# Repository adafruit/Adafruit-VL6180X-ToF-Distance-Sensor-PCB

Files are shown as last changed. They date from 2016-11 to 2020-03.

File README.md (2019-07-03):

## Adafruit VL6180X ToF Distance Sensor PCB

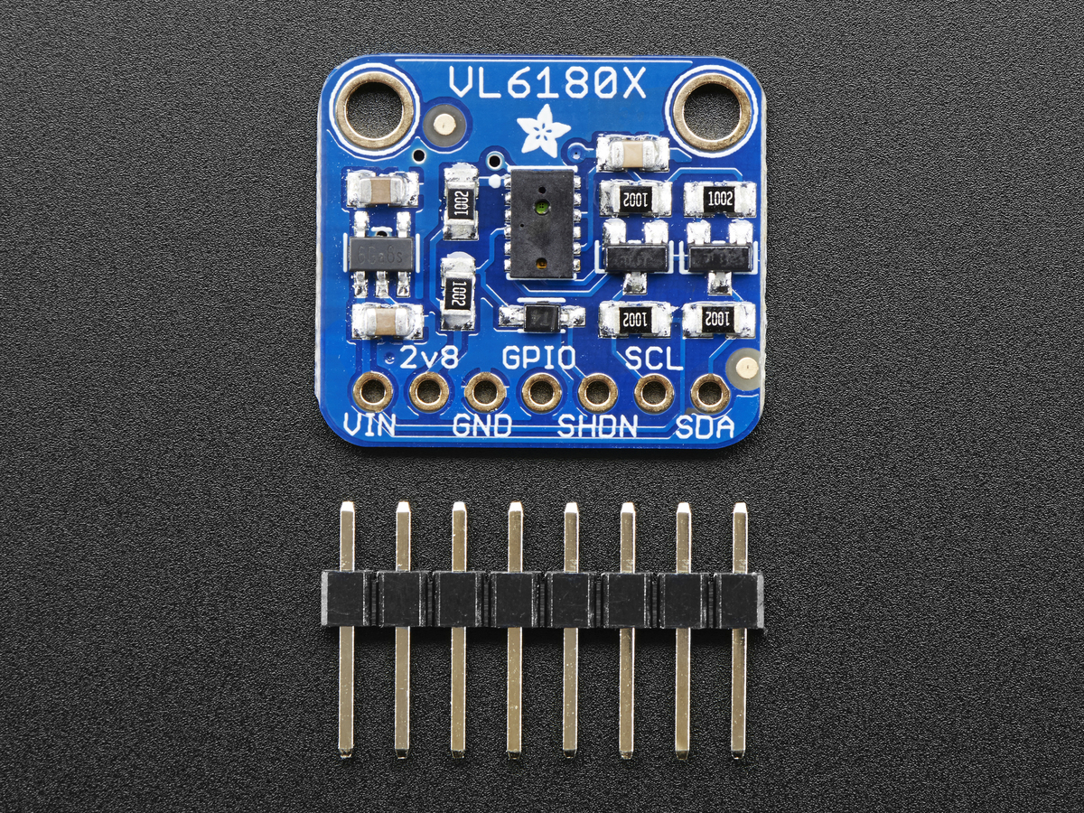
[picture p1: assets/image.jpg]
<a href="http://www.adafruit.com/products/3316"><br/>
Click here to purchase one from the Adafruit shop</a>

PCB files for the Adafruit VL6180X (VL6180) ToF Distance Sensor. Format is EagleCAD schematic and board layout

For more details, check out the product page at
* https://www.adafruit.com/product/3316

### Description

The VL6180X (sometimes called the VL6180) is a Time of Flight distance sensor like no other you've used! The sensor contains a very tiny laser source, and a matching sensor. The VL6180X can detect the "time of flight", or how long the laser light has taken to bounce back to the sensor. Since it uses a very narrow light source, it is good for determining distance of only the surface directly in front of it.

Unlike sonars that bounce ultrasonic waves, the 'cone' of sensing is very narrow. Unlike IR distance sensors that try to measure the amount of light bounced, the VL6180X is much more precise and doesn't have linearity problems or 'double imaging' where you can't tell if an object is very far or very close.

This is the 'little sister' of the Adafruit VL53L0X ToF sensor, and can handle about 5mm to 100mm of range distance. We've seen up to 150-200mm with good ambient conditions. It also includes a lux sensor. If you need a larger range, check out the VL53L0X which can measure 50 - 1200 mm.

The sensor is small and easy to use in any robotics or interactive project. Since it needs 2.8V power and logic we put the little fellow on a breakout board with a regulator and level shifting. You can use it with any 3-5V power or logic microcontroller with no worries. Each order comes with a small piece of header. Solder the header onto your breakout board with your iron and some solder and wire it up for instant distance-sensing-success!

Communicating to the sensor is done over I2C with some simple commands. Most of the work is handled inside the sensor itself, so its very easy to port our Arduino library to another microcontroller.

### License

Adafruit invests time and resources providing this open source design, please support Adafruit and open-source hardware by purchasing products from [Adafruit](https://www.adafruit.com)!

Designed by Limor Fried/Ladyada for Adafruit Industries.

Creative Commons Attribution/Share-Alike, all text above must be included in any redistribution. See license.txt for additional details.

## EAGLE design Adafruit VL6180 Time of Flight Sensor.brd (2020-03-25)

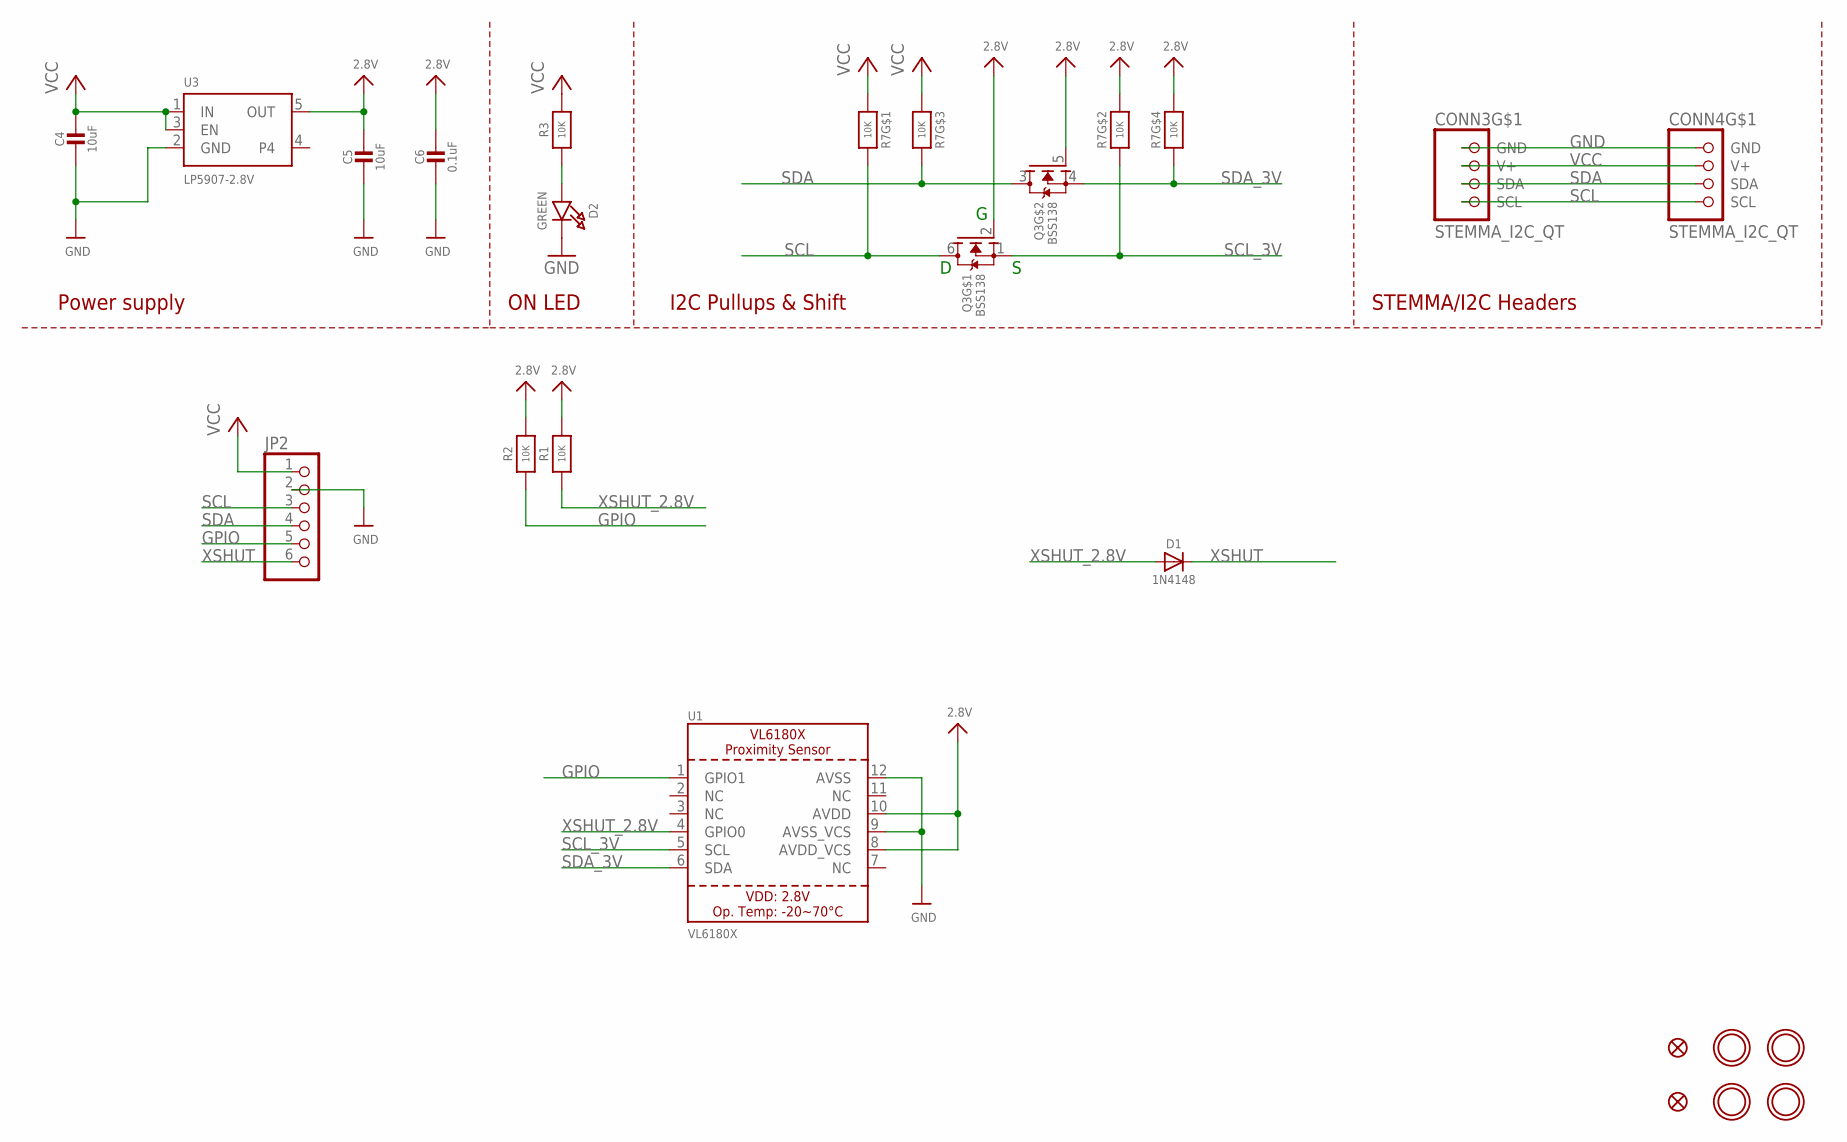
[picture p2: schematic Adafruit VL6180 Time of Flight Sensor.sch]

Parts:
C4, C5: 10uF; 0805-NO
C6: 0.1uF; 0603-NO
CONN3, CONN4: STEMMA_I2C_QT; JST_SH4
D1: 1N4148; SOD-323
D2: GREEN; CHIPLED_0603_NOOUTLINE
FID1, FID4: FIDUCIAL_1MM
JP2: HEADER-1X670MIL; 1X06_ROUND_70
Q3: BSS138; SOT363
R1, R2, R3: 10K; 0603-NO
R7: 10K; RESPACK_4X0603
U1: VL6180X; VL6180
U3: LP5907-2.8V; SOT23-5
U$30, U$31, U$33, U$34: MOUNTINGHOLE2.5; MOUNTINGHOLE_2.5_PLATED

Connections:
2.8V: C5.1, C6.1, Q3.2 (G), Q3.5 (G), R1.2, R2.2, R7.2 (1), R7.4 (1), U1.8 (AVDD_VCS), U1.10 (AVDD), U3.5 (OUT)
GND: C4.2, C5.2, C6.2, CONN3.1 (GND), CONN4.1 (GND), D2.C, JP2.2, U1.9 (AVSS_VCS), U1.12 (AVSS), U3.2 (GND)
GPIO: JP2.5, R2.1, U1.1 (GPIO1)
unnamed: D2.A, R3.1
SCL: CONN3.4 (SCL), CONN4.4 (SCL), JP2.3, Q3.6 (D), R7.8 (2)
SCL_3V: Q3.1 (S), R7.7 (2), U1.5 (SCL)
SDA: CONN3.3 (SDA), CONN4.3 (SDA), JP2.4, Q3.3 (D), R7.6 (2)
SDA_3V: Q3.4 (S), R7.5 (2), U1.6 (SDA)
VCC: C4.1, CONN3.2 (V+), CONN4.2 (V+), JP2.1, R3.2, R7.1, R7.3 (1), U3.1 (IN), U3.3 (EN)
XSHUT: D1.C, JP2.6
XSHUT_2.8V: D1.A, R1.1, U1.4 (GPIO0)

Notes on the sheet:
I2C Pullups & Shift
STEMMA/I2C Headers
ON LED
Power supply

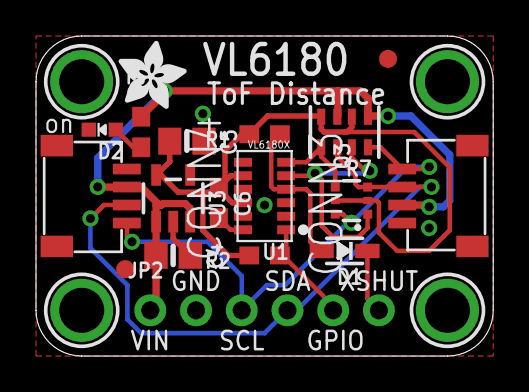
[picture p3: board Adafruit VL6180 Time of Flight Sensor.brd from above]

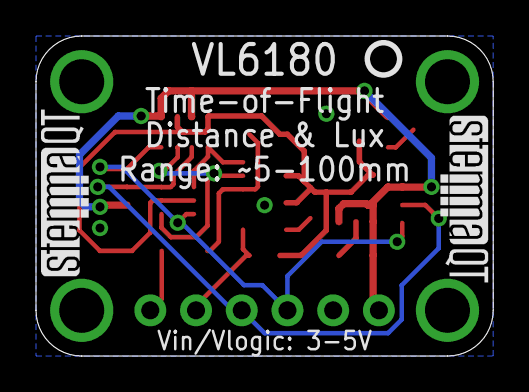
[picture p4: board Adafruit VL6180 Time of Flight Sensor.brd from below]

Board: 2 copper layers, 25.4 x 17.8 mm, 25 parts (3 on the bottom side), 11 nets.

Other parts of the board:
U$36: ADAFRUIT_3.5MM
U$37: PCBFEAT-REV-040
U$38, U$39: STEMMAQT

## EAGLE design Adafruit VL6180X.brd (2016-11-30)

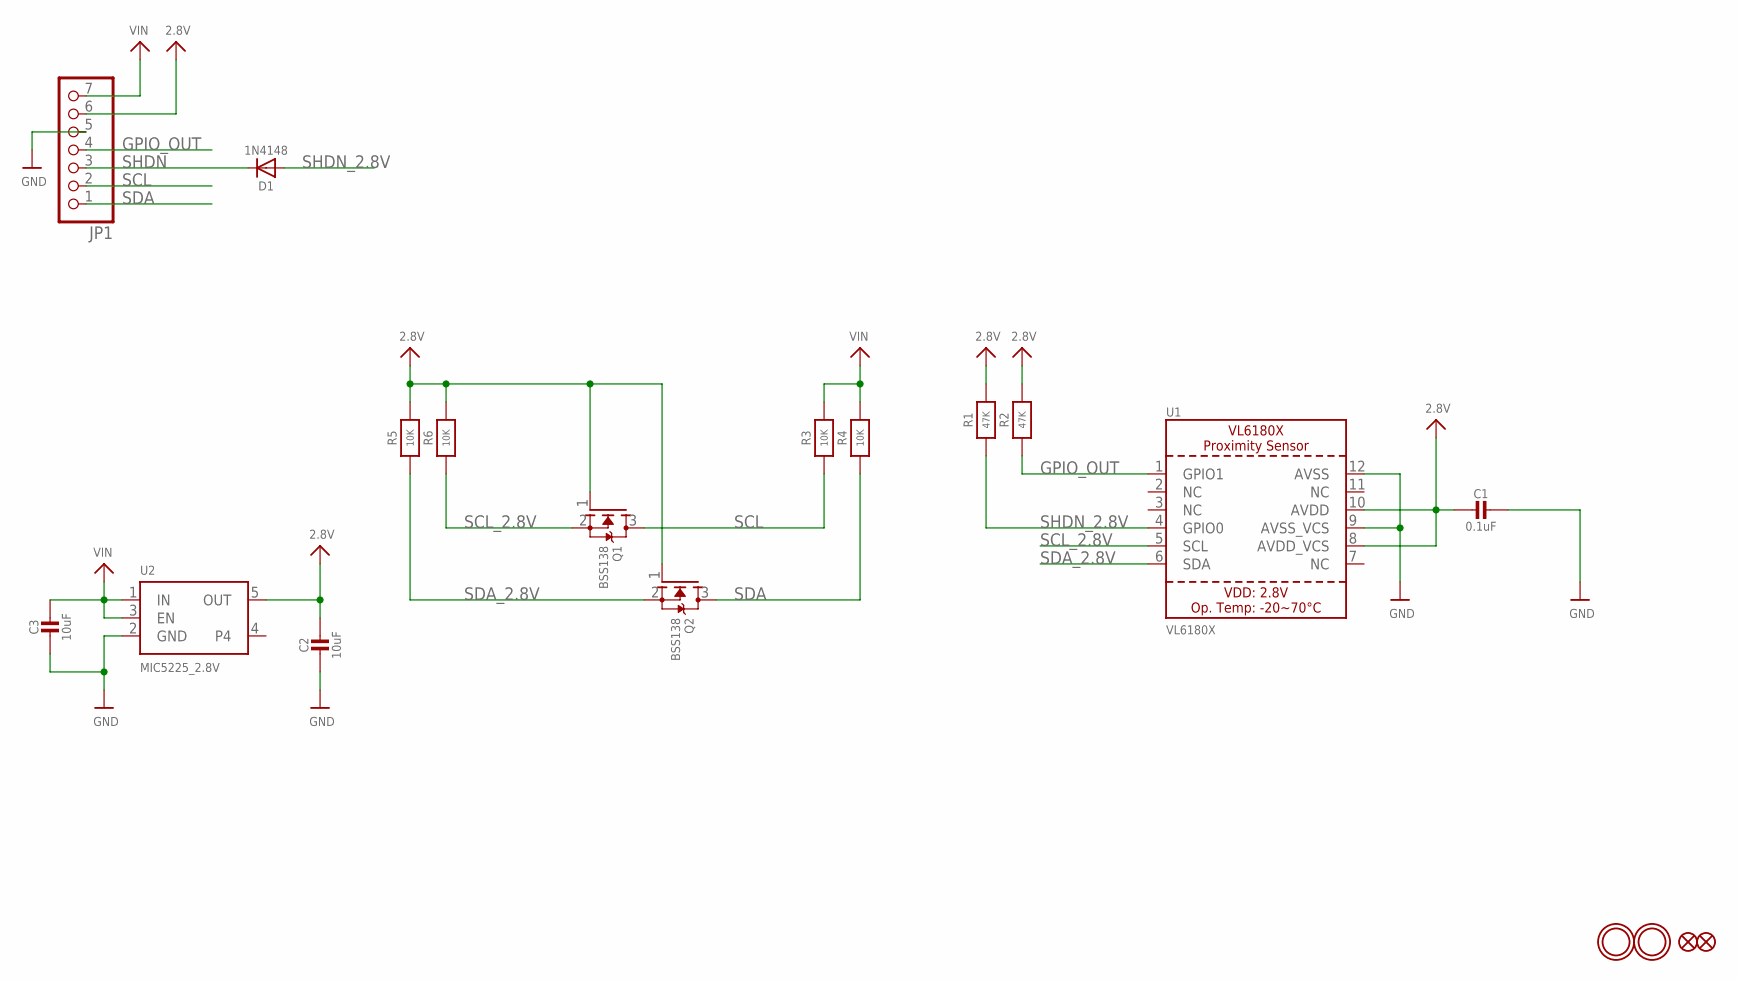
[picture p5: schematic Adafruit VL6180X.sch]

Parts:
C1: 0.1uF; 0805-NO
C2, C3: 10uF; 0805-NO
D1: 1N4148; SOD-323
FID1, FID2: FIDUCIAL""; FIDUCIAL_1MM
JP1: HEADER-1X770MIL; 1X07_ROUND_70
Q1, Q2: BSS138; SOT23-WIDE
R1, R2: 47K; 0805-NO
R3, R4, R5, R6: 10K; 0805-NO
U1: VL6180X; VL6180
U2: MIC5225_2.8V; SOT23-5
U$11, U$12: MOUNTINGHOLE2.5; MOUNTINGHOLE_2.5_PLATED

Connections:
2.8V: C1.2, C2.1, JP1.6, Q1.1 (G), Q2.1 (G), R1.2, R2.2, R5.2, R6.2, U1.8 (AVDD_VCS), U1.10 (AVDD), U2.5 (OUT)
GND: C1.1, C2.2, C3.2, JP1.5, U1.9 (AVSS_VCS), U1.12 (AVSS), U2.2 (GND)
GPIO_OUT: JP1.4, R2.1, U1.1 (GPIO1)
SCL: JP1.2, Q1.3 (D), R3.1
SCL_2.8V: Q1.2 (S), R6.1, U1.5 (SCL)
SDA: JP1.1, Q2.3 (D), R4.1
SDA_2.8V: Q2.2 (S), R5.1, U1.6 (SDA)
SHDN: D1.C, JP1.3
SHDN_2.8V: D1.A, R1.1, U1.4 (GPIO0)
VIN: C3.1, JP1.7, R3.2, R4.2, U2.1 (IN), U2.3 (EN)

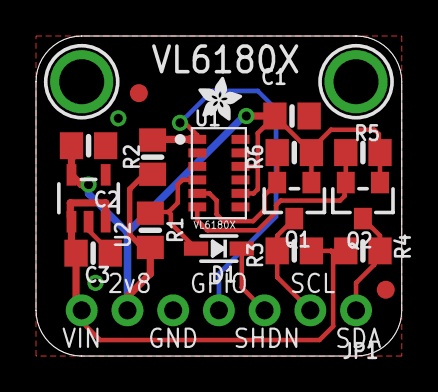
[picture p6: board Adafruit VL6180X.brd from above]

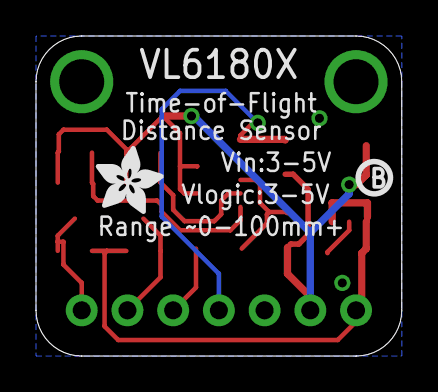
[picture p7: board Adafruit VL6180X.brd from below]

Board: 2 copper layers, 20.3 x 17.8 mm, 22 parts (2 on the bottom side), 10 nets.

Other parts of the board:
U$18: ADAFRUIT_2.5MM
U$20: ADAFRUIT_3.5MM
U$21: PCBFEAT-REV-040

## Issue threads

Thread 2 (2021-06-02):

Offset registry missing

ajsb85, 2021-06-02:
**Application note AN4545**
_VL6180X basic ranging application note_

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

Other libraries that support this settings:

https://github.com/sparkfun/SparkFun_ToF_Range_Finder-VL6180_Arduino_Library
https://github.com/pololu/vl6180x-arduino

ajsb85, 2021-06-02:
Sorry, I moved the issue to the library
https://github.com/adafruit/Adafruit_VL6180X/issues/21

Closed 2021-06-02.

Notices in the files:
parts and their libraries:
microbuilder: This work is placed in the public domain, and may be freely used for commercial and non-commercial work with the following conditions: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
